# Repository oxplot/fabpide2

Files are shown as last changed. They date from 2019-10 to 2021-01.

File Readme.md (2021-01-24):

**[See the newer fpx module](https://github.com/oxplot/fpx)**

**If you're looking for a similar board to this, checkout [Sparkfun's
Power Delivery Board](https://www.sparkfun.com/products/15801).**

---

fabpide2 is a PCB kit that breaks out Stand-alone USB PD sink controller
[STUSB4500](https://www.st.com/en/interfaces-and-transceivers/stusb4500.html)
by STMicroelectronics.

You can [buy this kit from
tindie](https://www.tindie.com/products/18263/).

See [my blog
post](https://blog.oxplot.com/usb-pd-standalone-sink-controller/) for a
bit of background.

# Flashing configuration with Arduino

One way to use STUSB4500 is to flash desired PDO configurations in its
NVM and it will work autonomously from then on. To use the chip in this
manner:

1. Open the [arduino
   flasher](arduino/stusb4500_flasher/stusb4500_flasher.ino) in Arduino
   IDE.

2. Install the [Software I2C library in this
   repo](arduino/libs/SoftI2CMaster.zip) on your Arduino IDE (via Sketch
   menu -> Include Library -> Add .ZIP library) — *note: adding the
   library may automatically add `#include` lines at the top of the sketch -
   be sure to remove those*

3. Follow the comments on the top of the sketch.

# Control via uC

Another way to use STUSB4500 is to connect it to an external uC to
dynamically control the chip and respond to events.

[Andrew](https://github.com/ardnew) has implemented an [Arduino
library](https://github.com/ardnew/STUSB4500)
called `STUSB4500` which is available in the official Arduino IDE
repository and can be installed from inside the IDE.

# Is this open source?

Yes. You can find the gerber files for revision 2 under `gerber/`
directory.



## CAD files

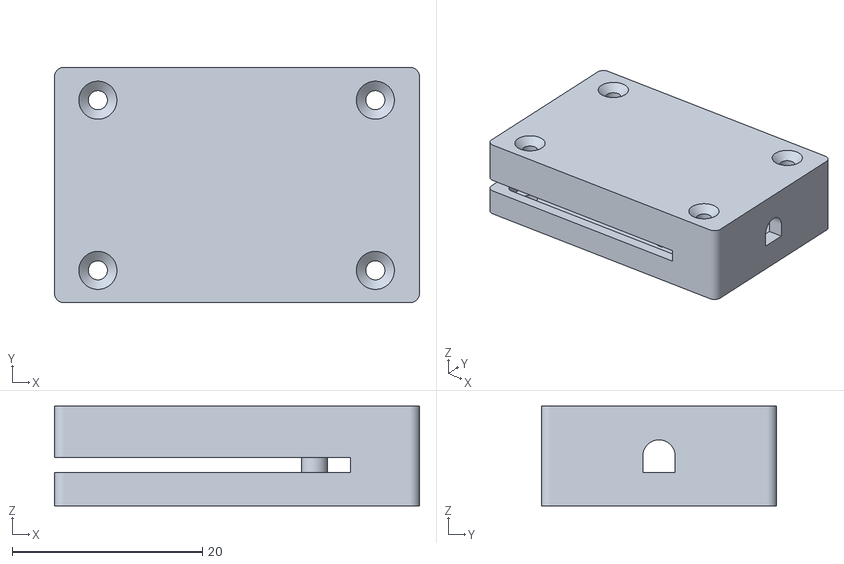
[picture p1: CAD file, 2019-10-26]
fabpide2-case.stl
38.4 x 24.8 x 10.5

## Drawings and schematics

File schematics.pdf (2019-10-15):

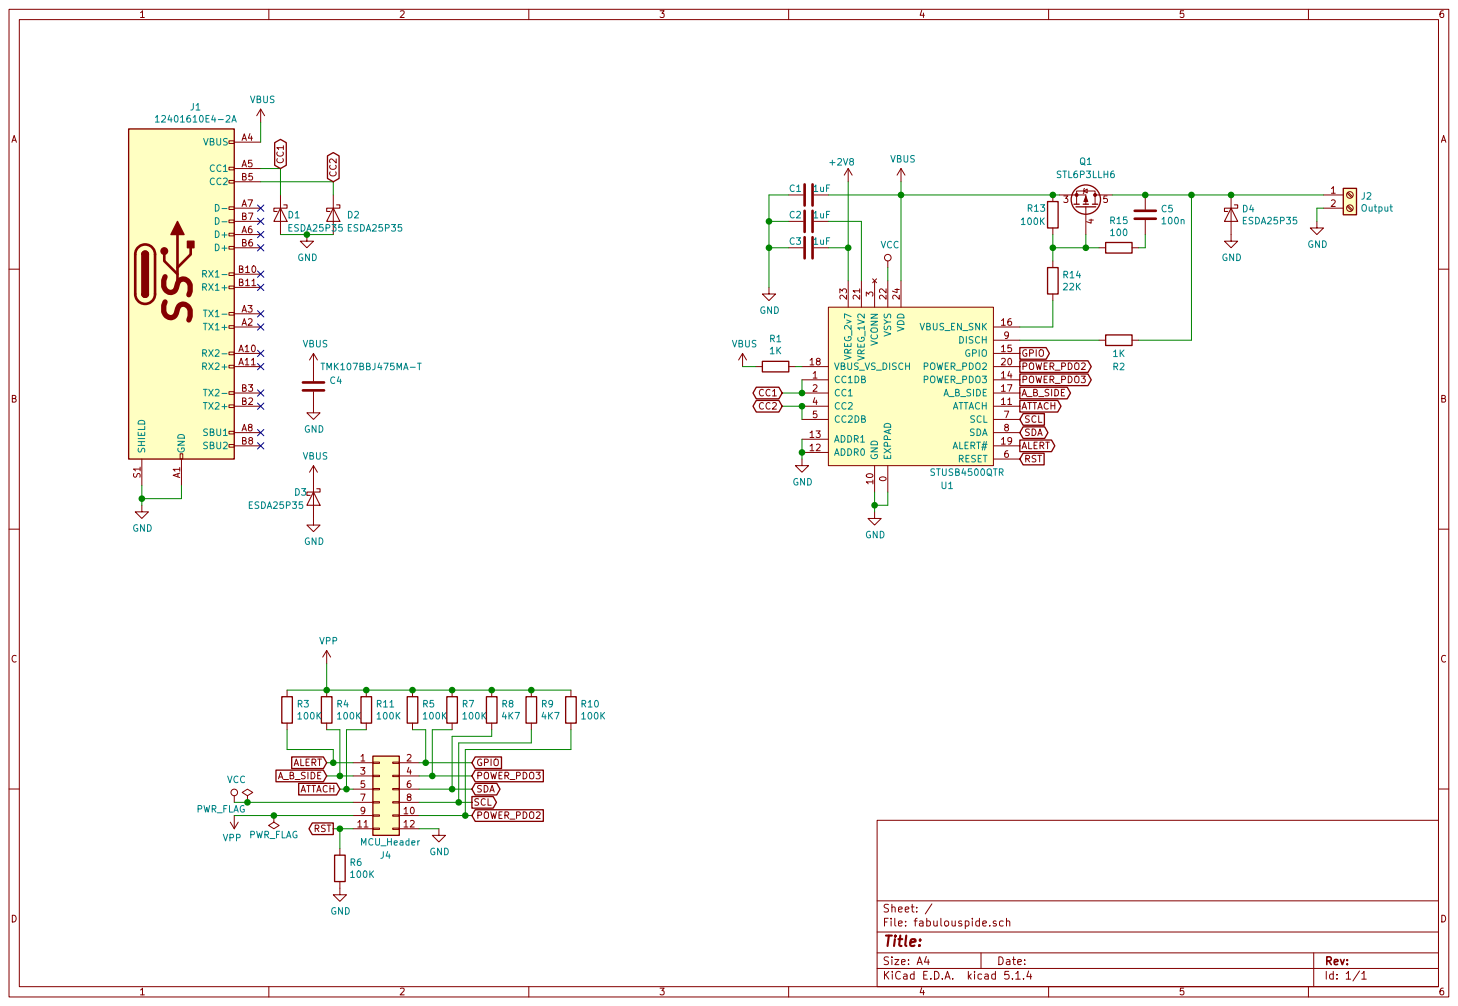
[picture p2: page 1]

0 CC1DB 1 GND 10 ATTACH 11 ADDR0 12 ADDR1 13 POWER_PDO3 14 GPIO 15 VBUS_EN_SNK 16 A_B_SIDE 17 VBUS_VS_DISCH 18 ALERT# 19 CC1 2 POWER_PDO2 20 VREG_1V2 21 VSYS 22 VREG_2v7 23 VDD 24 VCONN

3 CC2 4 CC2DB 5 RESET 6 SCL 7 SDA 8 DISCH 9 U1 STUSB4500QTR

File: fabulouspide.sch Sheet: / R5

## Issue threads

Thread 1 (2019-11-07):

Board design

x893, 2019-11-07:
Hi,
looks interesting !
Wait for board files for DIY.

Good luck for u

oxplot, 2019-11-28:
Fixed in https://github.com/oxplot/fabpide2/commit/4e7e8ebf4e9c805e6043a3d0fef2f2445cf8589e

x893, 2019-11-28:
Thanks !

Closed 2019-11-28.

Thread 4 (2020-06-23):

Resistor Numbering Skips 12

BrendanMcCallum, 2020-06-23:
This is very minor, and may have already been fixed in a more recent revision, but 12 is skipped in the numbering of resistors. I don't believe I have overlooked anything, but let me know if I have.

oxplot, 2020-06-24:
Thanks Brendan. Is it bad practice to have gaps in numbering?

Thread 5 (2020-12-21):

Trouble flashing NVM

DatanoiseTV, 2020-12-21:
I've made a board which uses the STUSB4500 and trying to flash it with a Arduino Duemilanove with SoftWire Wire(A0, A1) but it fails.

```
Press 'f' to flash the configuration ...
Flashing - hang on ...
Failed to set user password
FAILED flashing :(

```

Do you have any hints?

DatanoiseTV, 2020-12-21:
Now flashing was successful, but even though my USB PSU supports PD and is able to negotiate 15V or 20V with other devices, it fails to negotiate:

Schematic: https://imgur.com/pJCw2jW

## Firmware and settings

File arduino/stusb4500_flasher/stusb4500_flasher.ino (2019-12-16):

// stusb4500_flasher.ino - flash STUSB4500 NVM with configuration
// Ported to Arduino from https://github.com/usb-c/STUSB4500 and further configuration
// builder implemented on top.
//
// 1. Connect to fabpide2 board as following:
//
//   Arduino   | fabpide2
//   --------------------
//   SDA         SDA
//   SCL         SCL
//   5v/3.3v     VCC
//   5v/3.3v     VPP
//   GND         GND
//
// SDA and SCL pins are defined further below by macros. They can be any
// pin on the arduino as software I2C is used.
//
// 2. Set SDA_PIN & SCL_PIN to the pin number of the SDA and SCL on your board.
// 3. Set SDA_PORT & SCL_PORT to the port name of the SDA and SCL pins on your board.
//    * The default config is for Arduino Nano board.
// 4. Set appropriate values for the configuration macros below.
// 5. Upload the sketch and set serial monitor baud to 115200.
// 6. Follow the prompt.
//
/////////////////////////////////////////////////////////////////
// Config Macros
/////////////////////////////////////////////////////////////////
// * There are three PDOs (1, 2 and 3) each defining a voltage range and
//   max current. The voltage is defined with 50mV resolution between
//   5-20V and a lower and upper percentage range from 5%-20%. For
//   instance, when configured with 12V with 5% lower and 20% upper
//   threshold, supply voltages between 11.4-14.4V are accepted.
//
// * If PDO_COUNT is set to 3, PDO3 will be tried to match first. If
//   supply doesn't support the range and/or max. current, PDO2 will be
//   tried. If PDO2 cannot be satisfied, PDO 1 is tried like the other two
//   only if PDO1_ENABLED is true.  Otherwise, the power path is disabled
//   and no power is supplied to downstream.
//
// * If number of PDOs is set to 2 or 1, the matching starts at the
//   corresponding PDO and goes down to 1, ignoring higher PDO profiles.
//
// * PDO1's voltage is 5V and cannot be changed. Max. current for all
//   PDOs can be set to range 0.5-5A in at specific values. It can
//   optionally be set to CURRENT_FLEX which can be defined on a more
//   granular level.
//
// * Other config parameters are explained in further comments below.
/////////////////////////////////////////////////////////////////

// Max. current - note increments change from 0.25A to 0.5A toward the
// higher currents.
#define CURRENT_FLEX 0
#define CURRENT_0_50 1
#define CURRENT_0_75 2
#define CURRENT_1_00 3
#define CURRENT_1_25 4
#define CURRENT_1_50 5
#define CURRENT_1_75 6
#define CURRENT_2_00 7
#define CURRENT_2_25 8
#define CURRENT_2_50 9
#define CURRENT_2_75 10
#define CURRENT_3_00 11
#define CURRENT_3_50 12
#define CURRENT_4_00 13
#define CURRENT_4_50 14
#define CURRENT_5_00 15

// If enabled poll source for supported current at set voltage and
// pick highest supported current. When enabled set PDOx_CURRENT to
// lowest current needed
#define REQ_SRC_CURRENT false

// Flexible max. current value (0.005A resolution)
// Instead of using predefined CURRENT_* macros to set maximum current
// for a PDO, you can set the PDOx_CURRENT = CURRENT_FLEX which will
// set the maximum current to FLEX_CURRENT value.
#define FLEX_CURRENT 3.83

// Number of active PDO configs - between 1 and 3 inclusive.
#define PDO_COUNT 2

// Define your power requirements below in order of priority.
// PDOX_VOLTAGE_X_PERCENT can be whole numbers b/w 5 and 20 inclusive.
// PDOX_VOLTAGE can be from 0-20V with 0.05V resolution.
#define PDO3_VOLTAGE 20.00
#define PDO3_VOLTAGE_LOWER_PERCENT 7
#define PDO3_VOLTAGE_UPPER_PERCENT 9
#define PDO3_CURRENT CURRENT_5_00

#define PDO2_VOLTAGE 15.00
#define PDO2_VOLTAGE_LOWER_PERCENT 10
#define PDO2_VOLTAGE_UPPER_PERCENT 10
#define PDO2_CURRENT CURRENT_1_00

// PDO1's voltage is 5v and it cannot be changed.
#define PDO1_CURRENT CURRENT_FLEX
#define PDO1_VOLTAGE_UPPER_PERCENT 11
#define PDO1_ENABLED false

// Consult datasheet for details.
#define GPIO_FUNCTION_SW_CTRL_GPIO
#define GPIO_FUNCTION_ERROR_RECOVERY
#define GPIO_FUNCTION_DEBUG
#define GPIO_FUNCTION_SINK_POWER

// Sets function of the GPIO pin.
#define GPIO_FUNCTION GPIO_FUNCTION_SINK_POWER

// Discharge time in milliseconds between 84-1260ms inclusive.
#define VBUS_TO_0V_DISCHARGE_TIME 1000
// Discharge time in milliseconds between 24-360ms inclusive.
#define VBUS_TO_LOWER_PDO_DISCHARGE_TIME 200

/////////////////////////////////////////////////////////////////

// Set to appropriate pin and port of your arduino board. SDA and SCL pins
// need not be I2C pins of arduino as software I2C is used. Default values below
// are for Arduino Nano.
//
// Pinout for current (default) configuration
// Board   | Nano | Uno | Mega 2650
// SDA pin |    4 |  A4 |        33
// SCL pin |    5 |  A5 |        32
//
#define SDA_PIN 4
#define SCL_PIN 5
#define SDA_PORT PORTC
#define SCL_PORT PORTC

// These sector values are derived from the config macros above.
uint8_t Sector[5][8] = {
  {0x00, 0x00, 0xB0, 0xAA, 0x00, 0x45, 0x00, 0x00},
  {
    0x10,
    0x40,
    0x00 | ((VBUS_TO_0V_DISCHARGE_TIME / 84) << 4) | (VBUS_TO_LOWER_PDO_DISCHARGE_TIME / 24),
    0x1C,
    0xFF,
    0x01,
    0x3C,
    0xDF
  },
  {0x02, 0x40, 0x0F, 0x00, 0x32, 0x00, 0xFC, 0xF1},
  {
    0x00,
    0x19,
    0x00 | (PDO1_CURRENT << 4) | (PDO_COUNT << 1),
    0x0F | ((PDO1_VOLTAGE_UPPER_PERCENT - 5) << 4),
    0x00 | (PDO2_CURRENT) | ((PDO2_VOLTAGE_LOWER_PERCENT - 5) << 4),
    0x00 | (PDO3_CURRENT << 4) | (PDO2_VOLTAGE_UPPER_PERCENT - 5),
    0x00 | ((PDO3_VOLTAGE_UPPER_PERCENT - 5) << 4) | (PDO3_VOLTAGE_LOWER_PERCENT - 5),
    0x00
  },
  {
    0x00 | ((int)(PDO2_VOLTAGE * 20) & 0b11) << 6,
    0x00 | ((int)(PDO2_VOLTAGE * 20) >> 2),
    0x90 | ((int)(PDO3_VOLTAGE * 20) & 0xFF),
    0x00 | (((int)(FLEX_CURRENT * 200) & 0b1111111) << 1) | ((int)(PDO3_VOLTAGE * 20) >> 8),
    0x40 | ((int)(FLEX_CURRENT * 200) >> 7),
    0x00,
    0x40 | (PDO1_ENABLED ? 0 : 8) | (REQ_SRC_CURRENT ? 16 : 0),
    0xFB
  }
};

#include <SoftWire.h>

#define FTP_CUST_PASSWORD_REG 0x95
#define FTP_CUST_PASSWORD 0x47
#define FTP_CTRL_0 0x96
#define FTP_CUST_PWR 0x80 
#define FTP_CUST_RST_N 0x40
#define FTP_CUST_REQ 0x10
#define FTP_CUST_SECT 0x07
#define FTP_CTRL_1 0x97
#define FTP_CUST_SER 0xF8
#define FTP_CUST_OPCODE 0x07
#define RW_BUFFER 0x53

#define READ 0x00
#define WRITE_PL 0x01
#define WRITE_SER 0x02
#define READ_PL 0x03
#define READ_SER 0x04
#define ERASE_SECTOR 0x05
#define PROG_SECTOR 0x06
#define SOFT_PROG_SECTOR 0x07

#define SECTOR_0 0x01
#define SECTOR_1 0x02
#define SECTOR_2 0x04
#define SECTOR_3 0x08
#define SECTOR_4 0x10

#define I2C_ADDRESS 0x28

#define DEBUG

SoftWire Wire = SoftWire();

void setup() {
  Wire.begin();
  Serial.begin(115200);

#ifdef DEBUG
  for (int i = 0; i < 5; i++) {
    for (int j = 0; j < 8; j++) {
      printHex(Sector[i][j]);
      Serial.print("\t");
    }
    Serial.println();
  }
#endif
}

void loop() {
  uint8_t buf[40];

  delay(1000);
  Serial.println();
  Serial.println("Press 'f' to flash the configuration ...");
  while(!Serial.available() || Serial.read() != 'f');
  Serial.println("Flashing - hang on ...");

  if (nvm_flash() != 0) {
    Serial.println("FAILED flashing :(");
    return;
  }

  Serial.println("Verifying - hang on some more ...");
  if (nvmRead(buf) != 0) {
    Serial.println("Failed to read the flash :(");
    return;
  }
  for (int i = 0; i < 5; i++) {
    if (!verifySector(Sector[i], &buf[8 * i])) { 
      Serial.println("Verification failed :(");
      return;
    }
  }
  Serial.println("All done! Yayyyy! :)");
}

bool verifySector(uint8_t* target, uint8_t* actual) {
  for (int i = 0; i < 8; i++) {
    if (actual[i] != target[i]) {
      return false;
    }
  }
  return true;
}

int chipWrite(uint8_t reg, uint8_t* data, uint8_t len) {
  Wire.beginTransmission((uint8_t) I2C_ADDRESS);
  if (Wire.write(reg) != 1) {
    return 1;
  }
  if (Wire.write(data, len) != len) {
    return 1;
  }
  int endStatus = Wire.endTransmission(true);
  if (endStatus != 0) {
    Serial.print("chipWrite end tx failed (");
    Serial.print(endStatus, HEX);
    Serial.println(")");
    return 1;
  }
  return 0;
}

int chipRead(uint8_t reg, uint8_t* buf, uint8_t len) {
  Wire.beginTransmission((uint8_t) I2C_ADDRESS);
  if (Wire.write((uint8_t) reg) != 1) {
    return 1;
  }
  if (Wire.endTransmission(false) != 0) {
    return 1;
  }
  Wire.requestFrom((uint8_t) I2C_ADDRESS, (uint8_t) len, (uint8_t) true);
  for (int i = 0; i < len; i++) {
    while (!Wire.available());
    buf[i] = Wire.read();
  }
  return 0;
}

int enterNVMReadMode() {
  uint8_t buf[2];
  buf[0] = FTP_CUST_PASSWORD;
  if (chipWrite(FTP_CUST_PASSWORD_REG, buf, 1) != 0) {
    Serial.println("Failed to write customer password");
    return 1;
  }
  buf[0] = 0;
  if (chipWrite(FTP_CTRL_0, buf, 1) != 0) {
    Serial.println("Failed to reset NVM internal controller");
    return 1;
  }
  buf[0] = FTP_CUST_PWR | FTP_CUST_RST_N;
  if (chipWrite(FTP_CTRL_0, buf, 1) != 0) {
    Serial.println("Failed to set PWR and RST_N bits");
    return 1;
  }
  return 0;
}

int enterNVMWriteMode(uint8_t erasedSector) {
  uint8_t buf[2];

  buf[0] = FTP_CUST_PASSWORD;
  if (chipWrite(FTP_CUST_PASSWORD_REG, buf, 1) != 0 ) {
    Serial.println("Failed to set user password");
    return 1;
  }

  buf[0] = 0 ;
  if (chipWrite(RW_BUFFER, buf, 1) != 0) {
    Serial.println("Failed to set null for partial erase feature");
    return 1;
  }

  buf[0] = 0;
  if (chipWrite(FTP_CTRL_0,buf,1) != 0 ) {
    Serial.println("Failed to reset NVM controller");
    return 1;
  }

  buf[0] = FTP_CUST_PWR | FTP_CUST_RST_N;
  if (chipWrite(FTP_CTRL_0,buf,1) != 0) {
    Serial.println("Failed to set PWR and RST_N bits");
    return 1;
  }
  
  
  buf[0] = ((erasedSector << 3) & FTP_CUST_SER) | ( WRITE_SER & FTP_CUST_OPCODE) ;
  if (chipWrite(FTP_CTRL_1, buf, 1) != 0) {
    Serial.println("Failed to write SER opcode");
    return 1;
  }
  
  buf[0] = FTP_CUST_PWR | FTP_CUST_RST_N | FTP_CUST_REQ ;
  if (chipWrite(FTP_CTRL_0, buf, 1) != 0 ) {
    Serial.println("Failed to write SER optcode");
    return 1;
  }

  do {
    if (chipRead(FTP_CTRL_0, buf, 1) != 0 ) {
      Serial.println("Failed to wait for execution");
      return 1;
    }
  } while(buf[0] & FTP_CUST_REQ);

  buf[0] = SOFT_PROG_SECTOR & FTP_CUST_OPCODE;
  if (chipWrite(FTP_CTRL_1, buf, 1) != 0 ) {
    Serial.println("Failed to set soft prog opcode");
    return 1;
  }

  buf[0] = FTP_CUST_PWR | FTP_CUST_RST_N | FTP_CUST_REQ ;
  if (chipWrite(FTP_CTRL_0, buf, 1) != 0 ) {
    Serial.println("Failed to load soft prog opcode");
    return 1;
  }

  do {
    if (chipRead(FTP_CTRL_0, buf, 1) != 0 ) {
      Serial.println("Failed waiting for execution");
      return 1;
    }
  } while(buf[0] & FTP_CUST_REQ);

  buf[0] = ERASE_SECTOR & FTP_CUST_OPCODE;
  if (chipWrite(FTP_CTRL_1, buf, 1) != 0) {
    Serial.println("Failed to set erase sector opcode");
    return 1;
  }

  buf[0] = FTP_CUST_PWR | FTP_CUST_RST_N | FTP_CUST_REQ ;
  if (chipWrite(FTP_CTRL_0, buf, 1)  != 0) {
    Serial.println("Failed to load erase sectors opcode");
    return 1;
  }

  do {
    if ( chipRead(FTP_CTRL_0, buf, 1) != 0 ) {
      Serial.println("Failed waiting for execution");
      return 1;
    }
  } while(buf[0] & FTP_CUST_REQ);
  
  return 0;
}

int writeNVMSector(uint8_t SectorNum, uint8_t *SectorData)
{
  uint8_t Buffer[2];

  if (chipWrite(RW_BUFFER, SectorData, 8) != 0) {
    return -1;
  }

  Buffer[0] = FTP_CUST_PWR | FTP_CUST_RST_N;
  if (chipWrite(FTP_CTRL_0, Buffer, 1) != 0) {
    return -1;
  }

  Buffer[0] = WRITE_PL & FTP_CUST_OPCODE;
  if (chipWrite(FTP_CTRL_1, Buffer, 1) != 0) {
    return -1;
  }

  Buffer[0] = FTP_CUST_PWR |FTP_CUST_RST_N | FTP_CUST_REQ;
  if (chipWrite(FTP_CTRL_0, Buffer, 1) != 0) {
    return -1;
  }

  do {
    if ( chipRead(FTP_CTRL_0,Buffer,1) != 0 )return -1;
  } while(Buffer[0] & FTP_CUST_REQ) ;

  Buffer[0] = PROG_SECTOR & FTP_CUST_OPCODE;
  if (chipWrite(FTP_CTRL_1, Buffer, 1) != 0) {
    return -1;
  }

  Buffer[0] = (SectorNum & FTP_CUST_SECT) | FTP_CUST_PWR | FTP_CUST_RST_N | FTP_CUST_REQ;
  if (chipWrite(FTP_CTRL_0, Buffer, 1) != 0) {
    return -1;
  }

  do {
      if ( chipRead(FTP_CTRL_0,Buffer,1) != 0 )return -1;
  } while(Buffer[0] & FTP_CUST_REQ);

  return 0;
}

int nvm_flash() {
  if (enterNVMWriteMode(SECTOR_0 | SECTOR_1 | SECTOR_2 | SECTOR_3 | SECTOR_4) != 0) {
    return -1;
  }
  for (int i = 0; i < 5; i++) {
    if (writeNVMSector(i, Sector[i]) != 0) {
      return -1;
    }
  }
  if (exitNVMMode() != 0) {
    return -1;
  }
  return 0;
}

int exitNVMMode() {
  uint8_t buf[2];
  buf[0] = FTP_CUST_RST_N;
  buf[1] = 0;
  if (chipWrite(FTP_CTRL_0, buf, 2) != 0) {
    Serial.println("Failed to exit NVM mode");
    return 1;
  }
  buf[0] = 0;
  if (chipWrite(FTP_CUST_PASSWORD_REG, buf, 1) != 0) {
    Serial.println("Failed to reset customer password");
    return 1;
  }
  return 0;
}

int readNVMSector(uint8_t num, uint8_t* data) {
  uint8_t buf[2];
  buf[0] = FTP_CUST_PWR | FTP_CUST_RST_N;
  if (chipWrite(FTP_CTRL_0, buf, 1) != 0) {
    Serial.println("Failed to set PWR and RST_N bits");
    return 1;
  }
  buf[0]= (READ & FTP_CUST_OPCODE);
  if (chipWrite(FTP_CTRL_1, buf, 1) != 0) {
    Serial.println("Failed to set read sectors opcode");
    return 1;
  }

  buf[0] = (num & FTP_CUST_SECT) | FTP_CUST_PWR | FTP_CUST_RST_N | FTP_CUST_REQ;
  if (chipWrite(FTP_CTRL_0, buf, 1) != 0 ) {
    Serial.println("Failed to read sectors opcode");
    return 1;
  }
  do {
    if (chipRead(FTP_CTRL_0, buf, 1) != 0) {
      Serial.println("Failed waiting for execution");
      return 1;
    }
  } while(buf[0] & FTP_CUST_REQ);

  if (chipRead(RW_BUFFER, &data[0], 8) != 0) {
    Serial.println("NVM read failed");
    return 1;
  }

  buf[0] = 0;
  if (chipWrite(FTP_CTRL_0, buf, 1) != 0) {
    Serial.println("Resetting controller failed");
    return 1;
  }
  
  return 0;
}

int nvmRead(uint8_t* out) {
  if (enterNVMReadMode() != 0) {
    Serial.println("Failed to enter NVM read mode");
    return 1;
  }
  for (int i = 0; i < 5; i++) {
    if (readNVMSector(i, out + (i * 8)) != 0) {
      Serial.println("Failed to read sector");
      return 1;
    }
  }
  if (exitNVMMode() != 0) {
    Serial.println("Failed to exit NVM read mode");
    return 1;
  }
  return 0;
}

void printHex(int v) {
  char tmp[10];
  sprintf(tmp, "0x%.2X", v);
  Serial.print(tmp);
}

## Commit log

2019-10-15 Use software I2C to work around read issues
    [stusb4500_flasher.ino]
2019-10-15 Include the official drivers
2019-10-26 Add case STL file
    [fabpide2-case.stl]
2019-11-28 Add rev 2 gerber files
    [fabulouspide-B_Cu.gbl, fabulouspide-B_Mask.gbs, fabulouspide-B_Paste.gbp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]
2019-12-12 Link to Andrew STM32 HAL driver repo
2020-01-23 Add link to Andrew's arduino library
